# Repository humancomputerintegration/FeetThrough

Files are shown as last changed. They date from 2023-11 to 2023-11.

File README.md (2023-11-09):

# FeetThrough: Electrotactile Foot Interface that Preserves Real-World Sensations

This is the repository for PCB schematics and code for electrical stimulation used in the "FeetThrough: Electrotactile Foot Interface that Preserves Real-World Sensations" paper (ACM UIST2023).

**Summary**: FeetThrough is an open-source device that allows you to control external applications. Its hardware is built on an ESP32 microcontroller (you can use your favorite microcontroller), a custom-built multiplexer, and an electrical stimulator (we used the medical-grade Rehastim). We provide schematics for electrodes, multiplexers, and simple Python codes for electrical stimulation. By implementing a multiplexer and preparing a stimulator, you can test electrical stimulation for feet. Regarding the details of the electrode design, please refer to our paper.

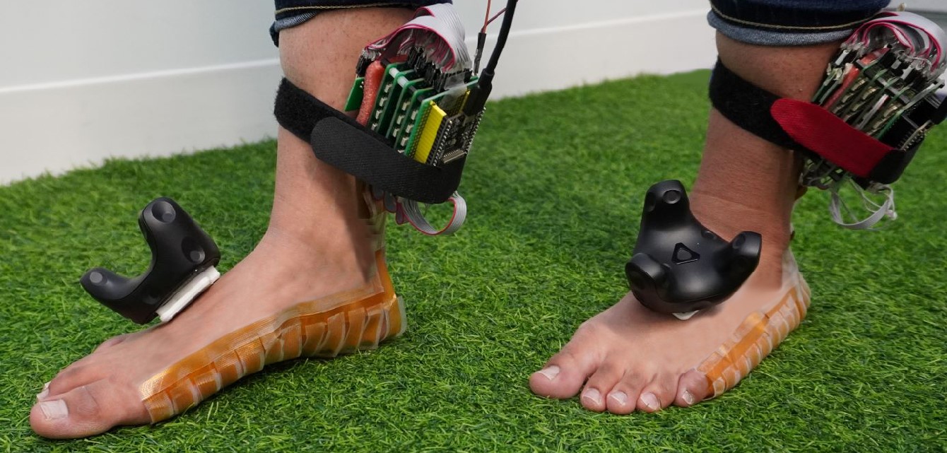
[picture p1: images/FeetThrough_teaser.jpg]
FeetThrough_image


## hardware

We share schematics of multiplexer board, flexible electrodes, and connector of the electrodes.

-  multiplexer: `hardware/photorelay_multiplexer`
   - This multiplexer is mainly consisted of shift registers (74HC595) and high-voltage photorelays (TLP176GA), and half-bridge configuration is created for each electrode

- electrodes: `hardware/electrodes` and `hardware/flexible_pcb_connector`
  - to use flexible electrodes, flexible PCB connector (FPC) is needed to deliver stimulation. We designed the end of the electrodes for this connector (FH12-30S-0.5SH(55), [mouser](https://mou.sr/3Qu7VoI)).
  - `app_electrodes_top` and `app_electrodes_bottom` are the final prototype of the electrodes to deliver stimulation to the whole sole. (To use 30-ch connector, the electrodes are separated in half)
  - To test the stimulator, you do not have to create flexible PCB electrodes. You can also use gel electrodes (often used for EMS) and other types of the electrodes if they are able to connect to the multiplexer

- stimulator (current source)
  - While we used the medical-grade RehaStim, you can use other electrical stimulators such as [RehaMove](https://github.com/humancomputerintegration/rehamove-integration-lib), [openEMSstim](https://github.com/PedroLopes/openEMSstim), [Electro-Tactile Display Kit for Fingertip (Kajimoto 2021)](https://ieeexplore.ieee.org/abstract/document/9517192).
  - connect the current source to `V+` and `V-` in the circuit.
  - We show another example of implementation with [a stimulator of Kajimoto 2021](https://ieeexplore.ieee.org/abstract/document/9517192)
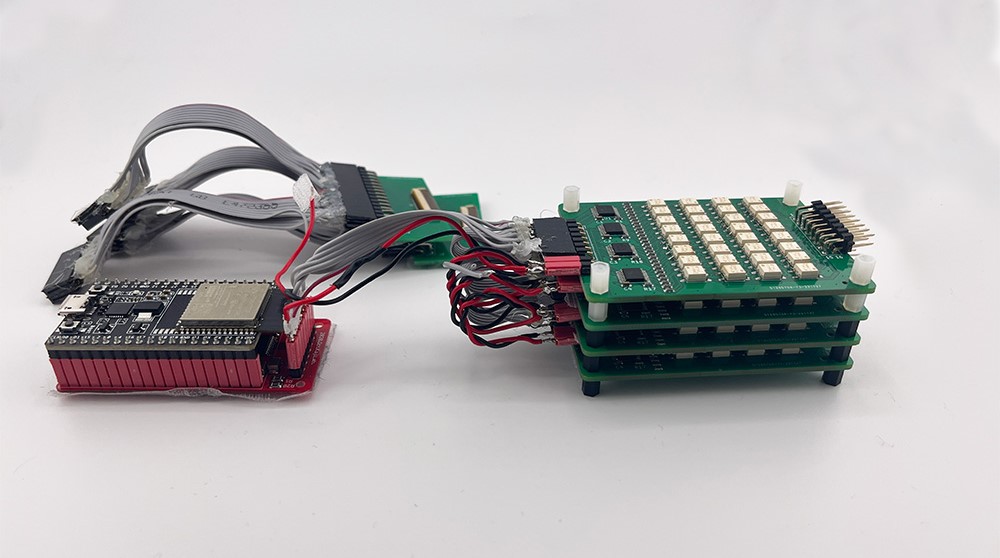
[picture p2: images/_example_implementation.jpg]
another_example_of_implementation
  - 

## source code

We share software code to stimulate multiple electrodes. To use the code, you have to prepare your stimulator and implement client for it. This code was developed for Windows 11

- client: `code/simple_stimulation`
  - `main.py`: simple controller of electrical stimulation
  - `custom_serial.py`: client for microcontroller of multiplexer
  - `photo_relay_switching.py`: Each channel of the multiplexer has three states (HIGH (V+), LOW (V-), OPEN (not connected)). This program manages and changes the states of multiplexer in software
  - `electro_stimulator.py`: client for electrical stimulator. This program controlls stimulation frequency and synchronize the timing between multiplexing and stimulator. 

in `electro_stimulator.py`, please change the code to use your stimulator

```python:electro_stimulator.py
# client for electrical stimulator ----- 
# NEED IMPLEMENTATION
client = ## please implement a client for your stimulator
## ------------------ 
```

```python:electro_stimulator.py
# --- send one pulse ---
# NEED IMPLEMENTATION
# client.write()
# --------
```

## how to use

- upload `arduino/multiplexer_esp32` to a microcontroller (ESP32 DevKitC 32E, [mouser](https://mou.sr/3GRjfHH)) through Arduino Software
  - before running the code, check and change `baudrate` and `com port` in `custom_serial.py`
- connect multiplexer and electrical stimulator to your PC
- run `main.py` in `code/simple_stimulation`

## contact

For any questions about this repository, please contact Keigo Ushiyama (ushiyama@kaji-lab.jp)

## citation

When using or building upon this work in an academic publication, please consider citing as follows:

Keigo Ushiyama and Pedro Lopes. 2023. FeetThrough: Electrotactile Foot Interface that Preserves Real-World Sensations. In Proceedings of the 36th Annual ACM Symposium on User Interface Software and Technology (UIST '23). Association for Computing Machinery, New York, NY, USA, Article 10, 1–11. https://doi.org/10.1145/3586183.3606808

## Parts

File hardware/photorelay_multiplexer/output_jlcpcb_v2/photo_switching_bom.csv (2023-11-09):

Comment | Designator | Footprint | JLCPCB Part #
0.1u | C1,C2,C3,C4 | Capacitor_SMD:C_0603_1608Metric | C14663
signals | J1 | Connector_PinSocket_2.54mm:PinSocket_1x07_P2.54mm_Vertical | C2932672
output | J2 | Connector_PinSocket_2.54mm:PinSocket_2x08_P2.54mm_Vertical | C239348
source | J3 | Connector_PinSocket_2.54mm:PinSocket_1x02_P2.54mm_Vertical | C2905414
470 | R1,R2,R3,R4,R5,R6,R7,R8,R9,R10,R11,R12,R13,R14,R15,R16,R17,R18,R19,R20,R21,R22,R23,R24,R25,R26,R27,R28,R29,R30,R31,R32 | Resistor_SMD:R_0603_1608Metric | C23179
74HC595 | U1,U10,U19,U20 | Package_SO:TSSOP-16_4.4x5mm_P0.65mm | C273642
TLP176GA | U2,U3,U4,U5,U6,U7,U8,U9,U11,U12,U13,U14,U15,U16,U17,U18,U21,U22,U23,U24,U25,U26,U27,U28,U29,U30,U31,U32,U33,U34,U35,U36 | keigo_custom_footprint:TLP176GA | C516859

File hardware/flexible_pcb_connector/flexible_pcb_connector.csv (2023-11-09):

Comment | Designator | Footprint | LCSC
Conn_01x30 | J1 | Connector_FFC-FPC:Hirose_FH12-30S-0.5SH_1x30-1MP_P0.50mm_Horizontal | C506793
Conn_01x30 | J2 | Connector_PinSocket_2.54mm:PinSocket_2x15_P2.54mm_Vertical

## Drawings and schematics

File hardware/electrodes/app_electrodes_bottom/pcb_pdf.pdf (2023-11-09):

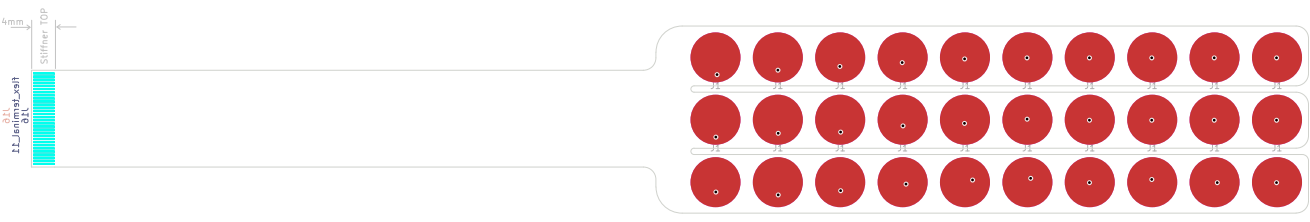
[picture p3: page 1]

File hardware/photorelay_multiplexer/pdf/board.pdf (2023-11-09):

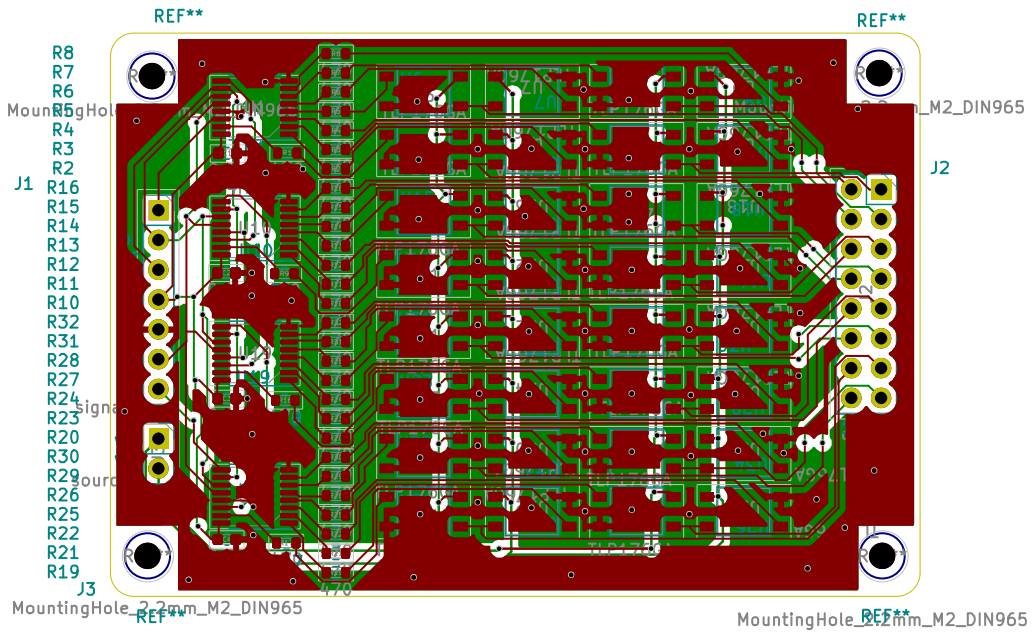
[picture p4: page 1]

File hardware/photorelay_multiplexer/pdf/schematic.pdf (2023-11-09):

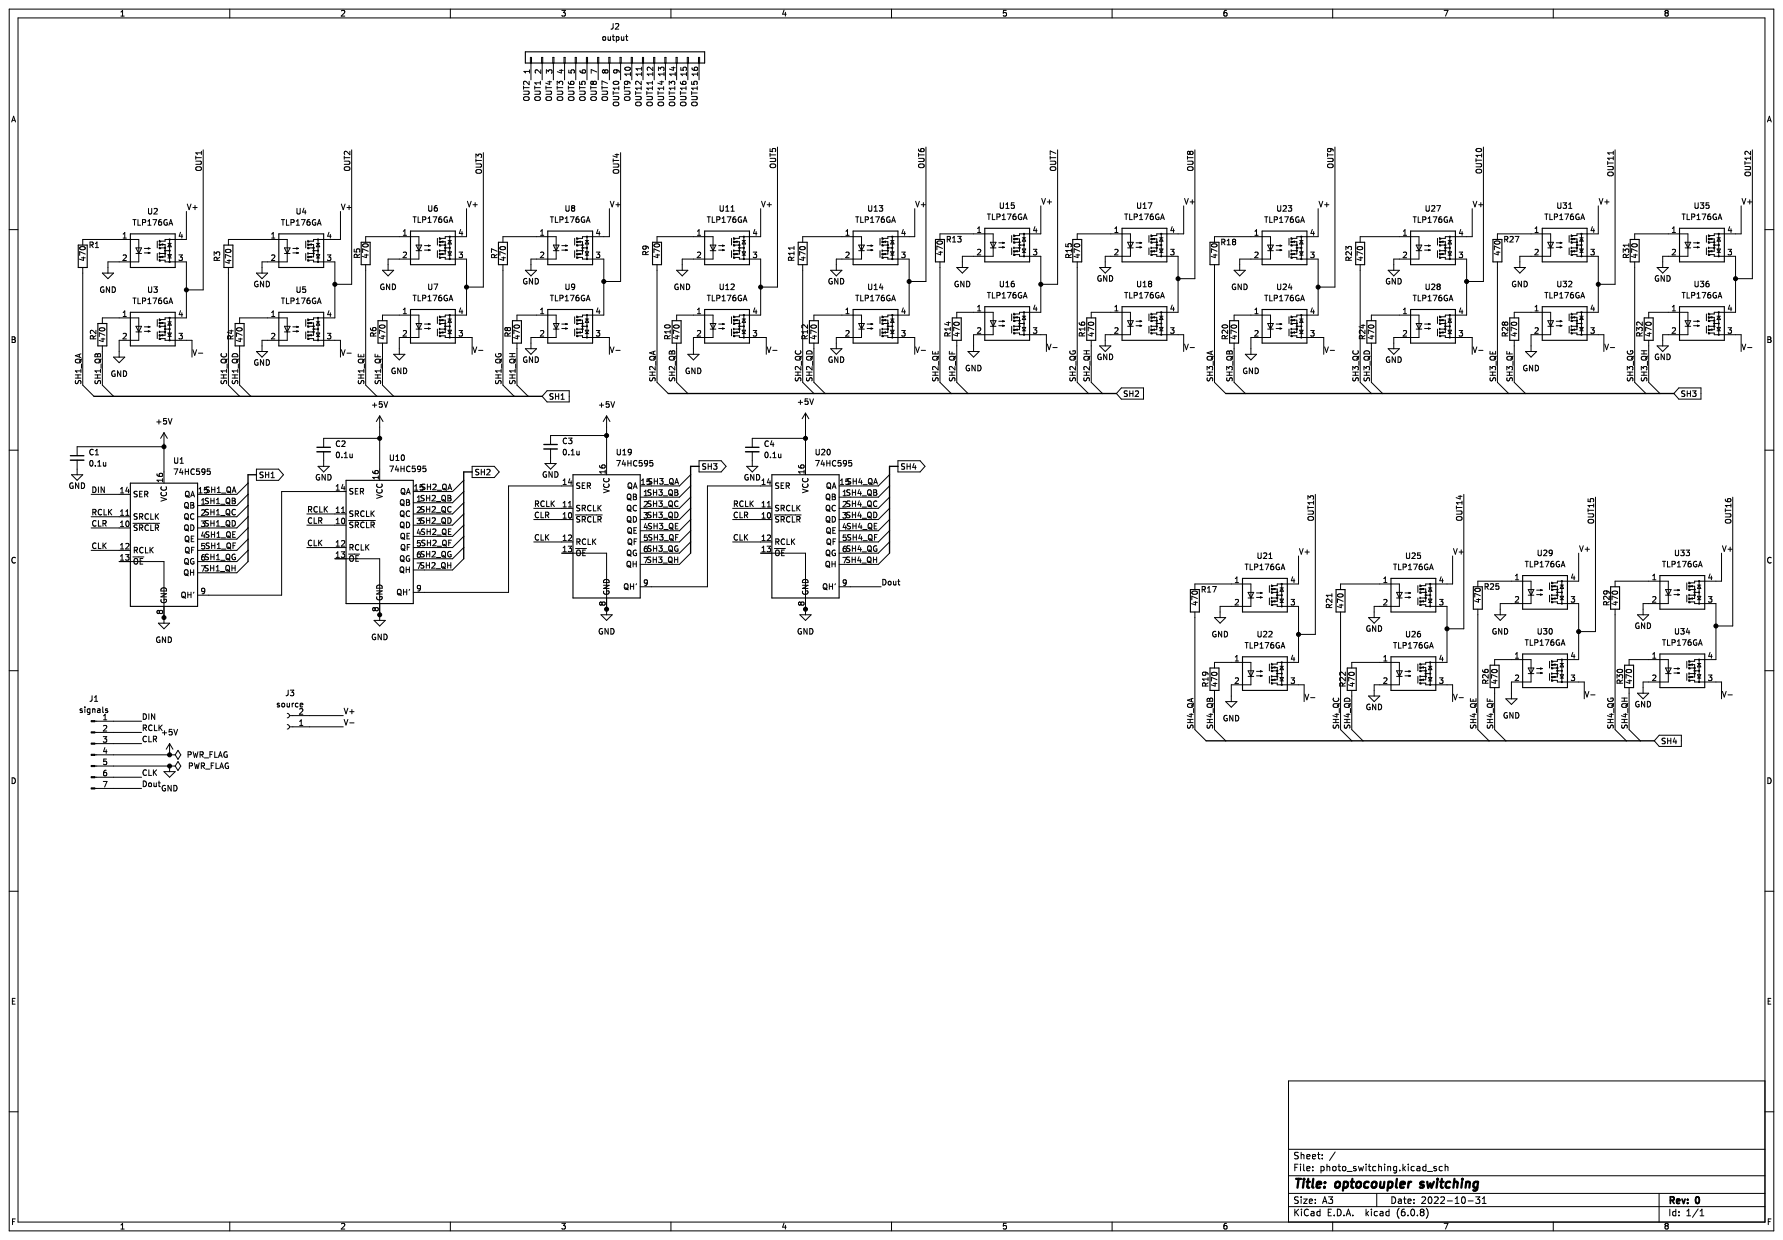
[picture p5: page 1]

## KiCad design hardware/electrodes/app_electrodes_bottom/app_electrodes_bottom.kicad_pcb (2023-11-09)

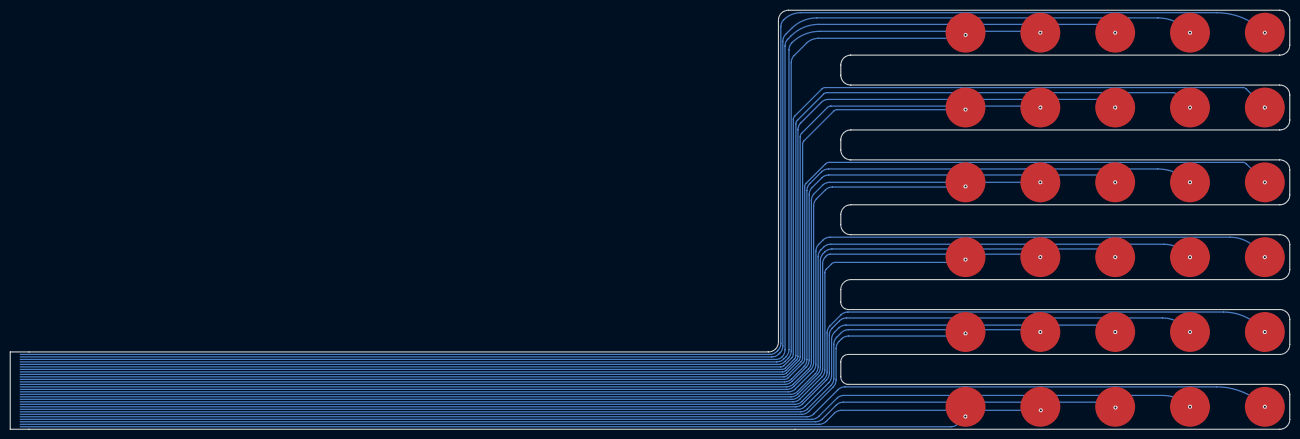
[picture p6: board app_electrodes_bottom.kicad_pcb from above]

Board: 2 copper layers, 256.5 x 84.0 mm, 31 parts (1 on the bottom side), 30 nets.

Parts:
J2, J3, J4, J5, J6, J8, J9, J10, J11, J12, J14, J15, J17, J18, J19, J21, J22, J23, J24, J25, J27, J28, J29, J30, J31, J32, J33, J34, J35, J36: electrode_pad; electrode_pad_smd
J16: flex_terminal_11; flex_hirose_30

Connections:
unnamed: J6.1, J16.1
unnamed: J8.10, J16.10
unnamed: J16.11, J19.11
unnamed: J16.12, J18.12
unnamed: J16.13, J17.13
unnamed: J15.14, J16.14
unnamed: J14.15, J16.15
unnamed: J5.2, J16.2
unnamed: J4.3, J16.3
unnamed: J3.4, J16.4
unnamed: J2.5, J16.5
unnamed: J12.6, J16.6
unnamed: J11.7, J16.7
unnamed: J10.8, J16.8
unnamed: J9.9, J16.9
unnamed: J16.16, J25.16
unnamed: J16.17, J24.17
unnamed: J16.18, J23.18
unnamed: J16.19, J22.19
unnamed: J16.20, J21.20
unnamed: J16.21, J31.21
unnamed: J16.22, J30.22
unnamed: J16.23, J29.23
unnamed: J16.24, J28.24
unnamed: J16.25, J27.25
unnamed: J16.26, J36.26
unnamed: J16.27, J35.27
unnamed: J16.28, J34.28
unnamed: J16.29, J33.29
unnamed: J16.30, J32.30

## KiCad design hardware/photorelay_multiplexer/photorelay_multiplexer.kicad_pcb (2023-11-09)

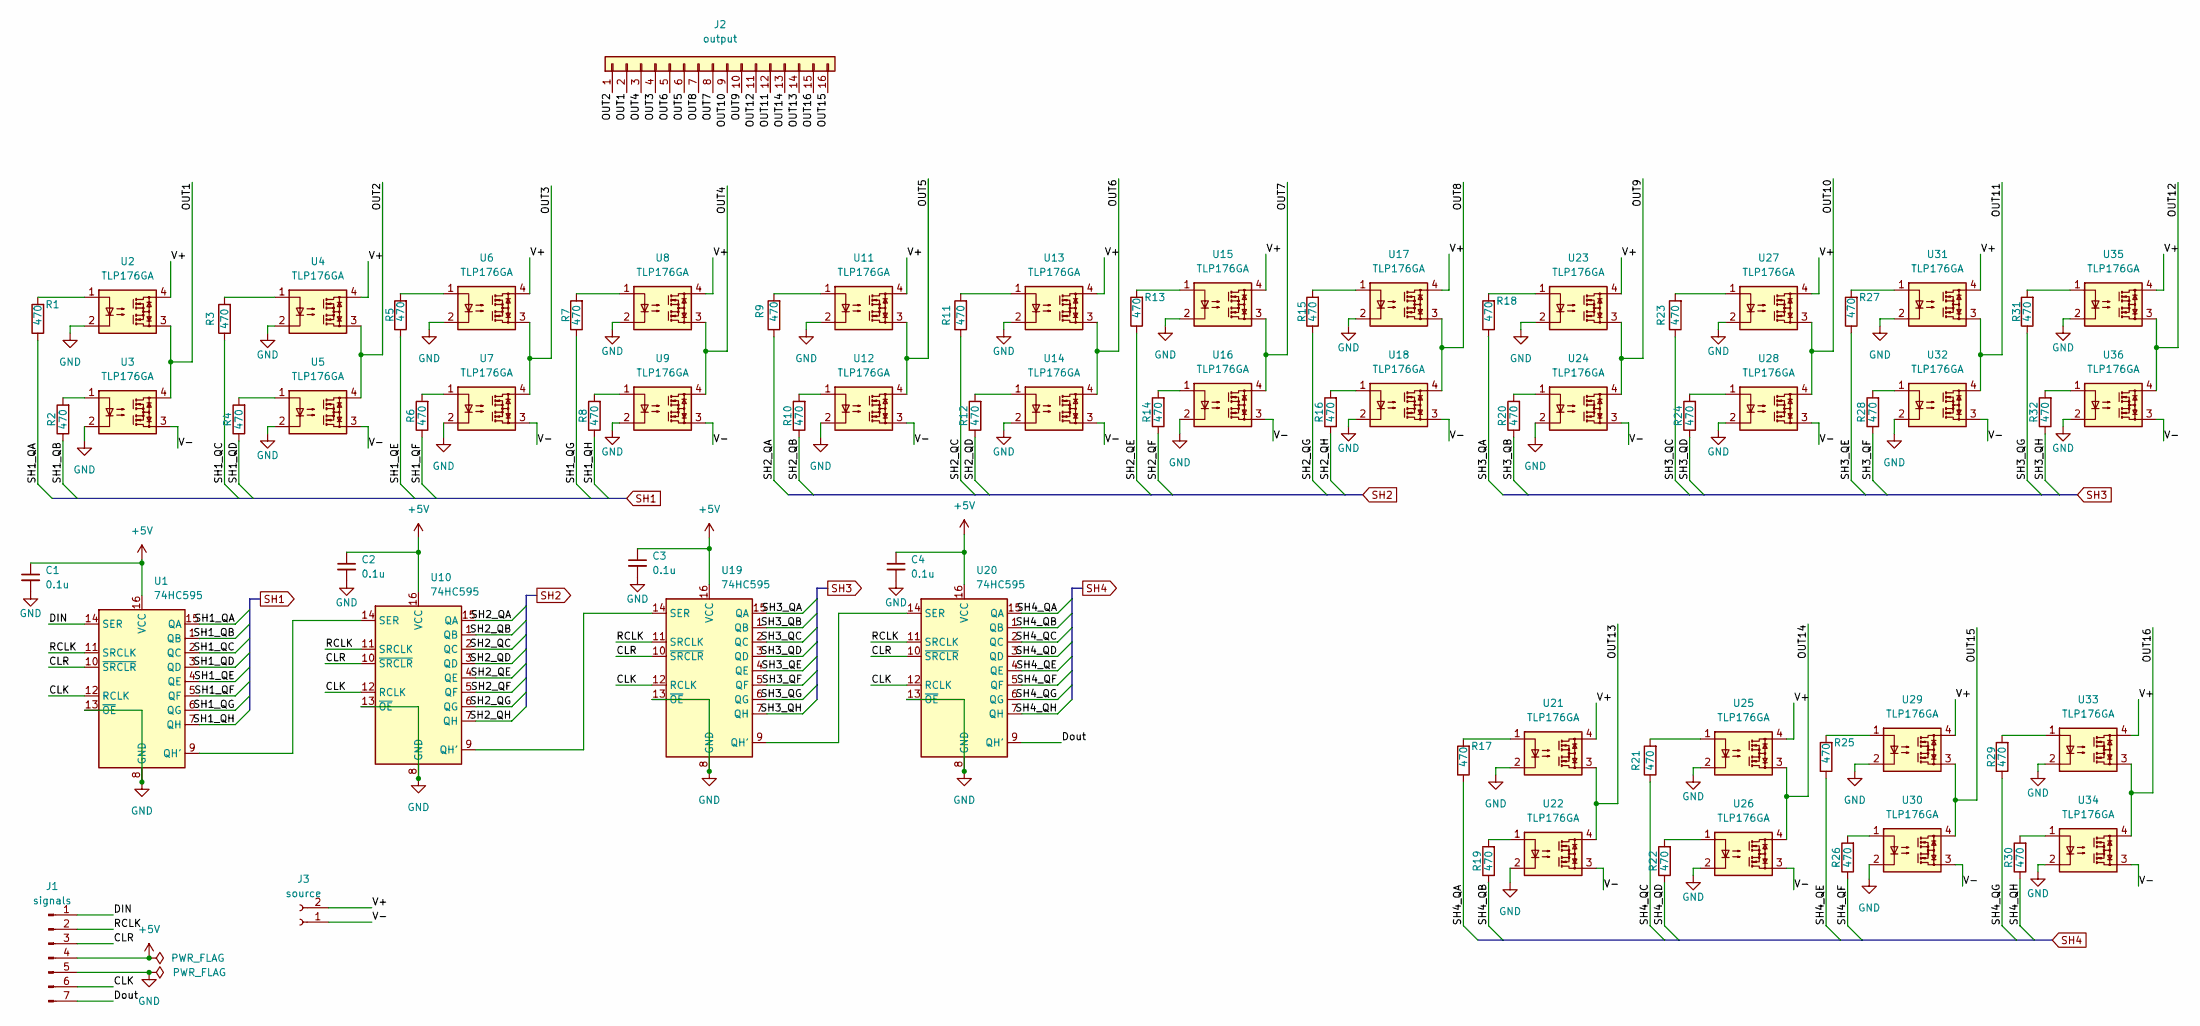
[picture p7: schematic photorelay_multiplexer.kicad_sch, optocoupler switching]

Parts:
C1, C2, C3, C4: 0.1u; C_0603_1608Metric
J1: signals; PinSocket_1x07_P2.54mm_Vertical
J2: output; PinSocket_2x08_P2.54mm_Vertical
J3: source; PinSocket_1x02_P2.54mm_Vertical
R1, R2, R3, R4, R5, R6, R7, R8, R9, R10, R11, R12, R13, R14, R15, R16, R17, R18, R19, R20, R21, R22, R23, R24, R25, R26, R27, R28, R29, R30, R31, R32: 470; R_0603_1608Metric
U1, U10, U19, U20: 74HC595; TSSOP-16_4.4x5mm_P0.65mm; LCSC C273642
U2: TLP176GA; LCSC C516859
U3, U4, U5, U6, U7, U8, U9, U11, U12, U13, U14, U15, U16, U17, U18, U21, U22, U23, U24, U25, U26, U27, U28, U29, U30, U31, U32, U33, U34, U35, U36: TLP176GA

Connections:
+5V: C1.1, C2.1, C3.1, C4.1, J1.4, U1.16 (VCC), U10.16 (VCC), U19.16 (VCC), U20.16 (VCC)
/CLK: J1.6, U1.12 (RCLK), U10.12 (RCLK), U19.12 (RCLK), U20.12 (RCLK)
/CLR: J1.3, U1.10 (~SRCLR), U10.10 (~SRCLR), U19.10 (~SRCLR), U20.10 (~SRCLR)
/DIN: J1.1, U1.14 (SER)
/Dout: J1.7, U20.9 (QH')
/OUT1: J2.2, U2.3, U3.4
/OUT2: J2.1, U4.3, U5.4
/OUT3: J2.4, U6.3, U7.4
/OUT4: J2.3, U8.3, U9.4
/OUT5: J2.6, U11.3, U12.4
/OUT6: J2.5, U13.3, U14.4
/OUT7: J2.8, U15.3, U16.4
/OUT8: J2.7, U17.3, U18.4
/OUT9: J2.10, U23.3, U24.4
/OUT10: J2.9, U27.3, U28.4
/OUT11: J2.12, U31.3, U32.4
/OUT12: J2.11, U35.3, U36.4
/OUT13: J2.14, U21.3, U22.4
/OUT14: J2.13, U25.3, U26.4
/OUT15: J2.16, U29.3, U30.4
/OUT16: J2.15, U33.3, U34.4
/RCLK: J1.2, U1.11 (SRCLK), U10.11 (SRCLK), U19.11 (SRCLK), U20.11 (SRCLK)
/SH1_QA: R1.1, U1.15 (QA)
/SH1_QB: R2.1, U1.1 (QB)
/SH1_QC: R3.1, U1.2 (QC)
/SH1_QD: R4.1, U1.3 (QD)
/SH1_QE: R5.1, U1.4 (QE)
/SH1_QF: R6.1, U1.5 (QF)
/SH1_QG: R7.1, U1.6 (QG)
/SH1_QH: R8.1, U1.7 (QH)
/SH2_QA: R9.1, U10.15 (QA)
/SH2_QB: R10.1, U10.1 (QB)
/SH2_QC: R11.1, U10.2 (QC)
/SH2_QD: R12.1, U10.3 (QD)
/SH2_QE: R13.1, U10.4 (QE)
/SH2_QF: R14.1, U10.5 (QF)
/SH2_QG: R15.1, U10.6 (QG)
/SH2_QH: R16.1, U10.7 (QH)
/SH3_QA: R18.1, U19.15 (QA)
/SH3_QB: R20.1, U19.1 (QB)
/SH3_QC: R23.1, U19.2 (QC)
/SH3_QD: R24.1, U19.3 (QD)
/SH3_QE: R27.1, U19.4 (QE)
/SH3_QF: R28.1, U19.5 (QF)
/SH3_QG: R31.1, U19.6 (QG)
/SH3_QH: R32.1, U19.7 (QH)
/SH4_QA: R17.1, U20.15 (QA)
/SH4_QB: R19.1, U20.1 (QB)
/SH4_QC: R21.1, U20.2 (QC)
/SH4_QD: R22.1, U20.3 (QD)
/SH4_QE: R25.1, U20.4 (QE)
/SH4_QF: R26.1, U20.5 (QF)
/SH4_QG: R29.1, U20.6 (QG)
/SH4_QH: R30.1, U20.7 (QH)
/V+: J3.2, U2.4, U4.4, U6.4, U8.4, U11.4, U13.4, U15.4, U17.4, U21.4, U23.4, U25.4, U27.4, U29.4, U31.4, U33.4, U35.4
/V-: J3.1, U3.3, U5.3, U7.3, U9.3, U12.3, U14.3, U16.3, U18.3, U22.3, U24.3, U26.3, U28.3, U30.3, U32.3, U34.3, U36.3
GND: C1.2, C2.2, C3.2, C4.2, J1.5, U1.8 (GND), U1.13 (~OE), U2.2, U3.2, U4.2, U5.2, U6.2, U7.2, U8.2, U9.2, U10.8 (GND), U10.13 (~OE), U11.2, U12.2, U13.2, U14.2, U15.2, U16.2, U17.2, U18.2, U19.8 (GND), U19.13 (~OE), U20.8 (GND), U20.13 (~OE), U21.2, U22.2, U23.2, U24.2, U25.2, U26.2, U27.2, U28.2, U29.2, U30.2, U31.2, U32.2, U33.2, U34.2, U35.2, U36.2
unnamed: R1.2, U2.1
unnamed: R2.2, U3.1
unnamed: R3.2, U4.1
unnamed: R4.2, U5.1
unnamed: R5.2, U6.1
unnamed: R6.2, U7.1
unnamed: R7.2, U8.1
unnamed: R8.2, U9.1
unnamed: R9.2, U11.1
unnamed: R10.2, U12.1
unnamed: R11.2, U13.1
unnamed: R12.2, U14.1
unnamed: R13.2, U15.1
unnamed: R14.2, U16.1
unnamed: R15.2, U17.1
unnamed: R16.2, U18.1
unnamed: R17.2, U21.1
unnamed: R18.2, U23.1
unnamed: R19.2, U22.1
unnamed: R20.2, U24.1
unnamed: R21.2, U25.1
unnamed: R22.2, U26.1
unnamed: R23.2, U27.1
unnamed: R24.2, U28.1
unnamed: R25.2, U29.1
unnamed: R26.2, U30.1
unnamed: R27.2, U31.1
unnamed: R28.2, U32.1
unnamed: R29.2, U33.1
unnamed: R30.2, U34.1
unnamed: R31.2, U35.1
unnamed: R32.2, U36.1
unnamed: U1.9 (QH'), U10.14 (SER)
unnamed: U10.9 (QH'), U19.14 (SER)
unnamed: U19.9 (QH'), U20.14 (SER)

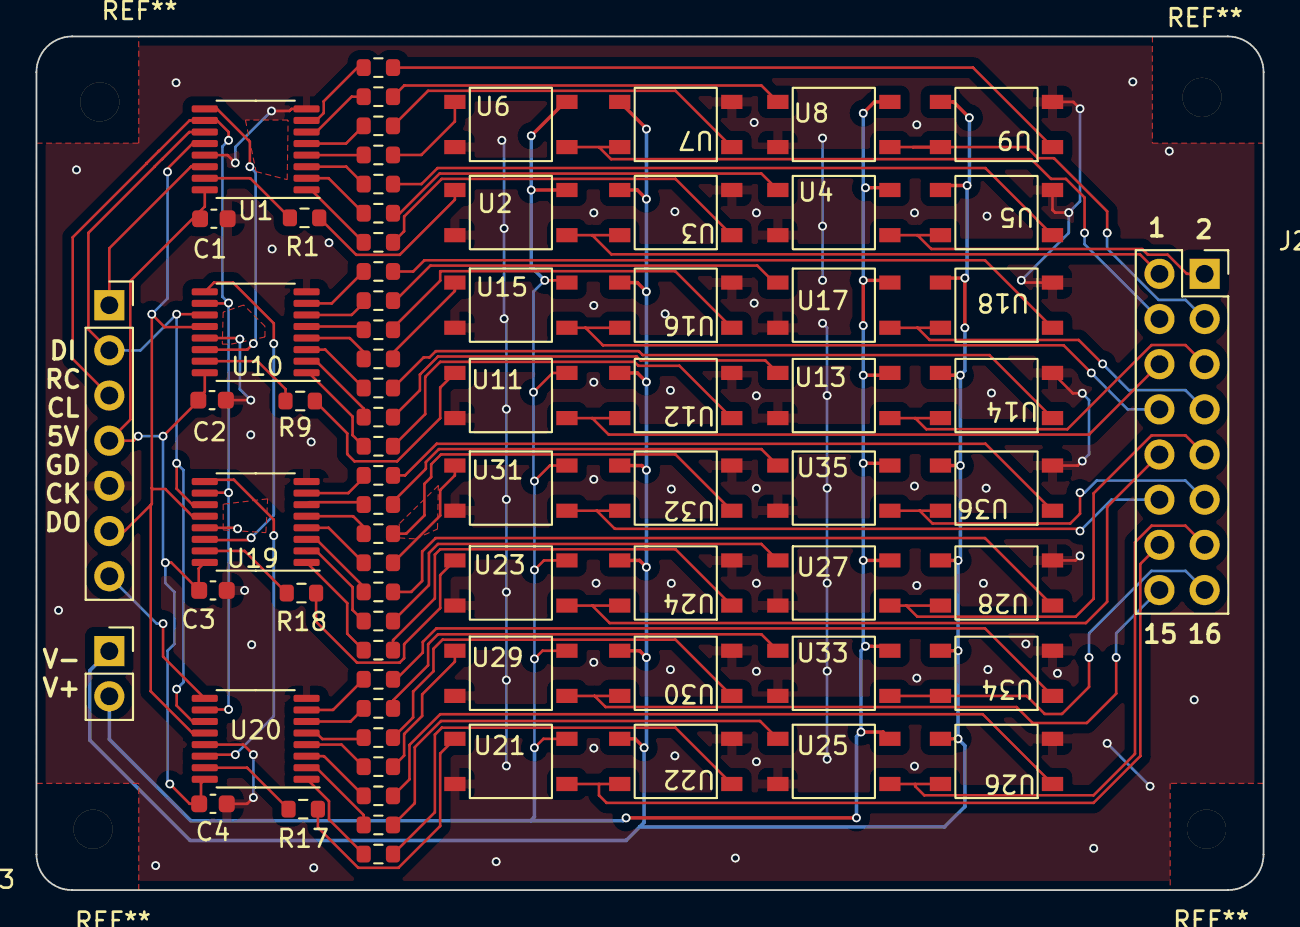
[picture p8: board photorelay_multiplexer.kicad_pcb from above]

Board: 2 copper layers, 69.0 x 48.0 mm, 75 parts (0 on the bottom side), 92 nets.

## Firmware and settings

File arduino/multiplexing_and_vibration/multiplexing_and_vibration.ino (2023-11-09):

// ----
// esp32 devkit c
// ---
#include <SPI.h>

// headers
const int ELECTRO = 0xFF;
const int VIBRO = 0xFE;

// for shift registers (optocoupler switching)
const int SR_SER = 32;
const int SR_CLK = 33;
const int SR_RCLK = 25;
const int SR_CLR = 26;
const int SR_OE = 27;

const int STATE_OPEN = 0;
const int STATE_GND = 1;
const int STATE_HIGH = 2;

// change this when you changed the number of boards!!
const int register_num = (8 * 4) * 4;
int register_state[register_num] = { 0 };

const int channel_num = register_num / 2;
int channel_state[channel_num] = { STATE_OPEN };
// -----


// for DACs and LRAs
// HSPI
const int m_HSCK = 14;
const int m_HMISO = 12;
const int m_HMOSI = 13;
const int m_HCS = 15;

// VSPI
const int m_VSCK = 18;
const int m_VMISO = 19;
const int m_VMOSI = 23;
const int m_VCS = 5;

// chip select by myself
const int m_CS1 = 16;
const int m_CS2 = 17;
const int SPI_FREQ = 10 * 1000 * 1000;

const int MAX_AMP = 1023;  // LTC1660 - 10bit
const int BASE_OFFSET = (1.0 / 5.0) * MAX_AMP;
const int BASE_AMP = 1023 - BASE_OFFSET;

const int CHANNELS = 16;  //10;


const int VIBRATION = 0xFF;
const int CALIBRATION = 0xFE;

const int TABLE_LEN = 10000;
int table_index = 0;
const int sampling_rate = 10000;
int vibration_intensities[CHANNELS];
//float sin_table[TABLE_LEN];
float square_table[TABLE_LEN];
hw_timer_t *counter_timer;


// stimulation parameters
int frequency = 175;  // Hz
int vibrate_flags[CHANNELS];

void IRAM_ATTR increment_index() {
  int increment = (int)(frequency * ((double)TABLE_LEN / (double)sampling_rate));
  table_index = (table_index + increment) % TABLE_LEN;
}

// ------ electrical stimulation -----
void set_all_channel() {
  digitalWrite(SR_CLK, LOW);
  digitalWrite(SR_RCLK, LOW);

  for (int i = 0; i < channel_num; i++) {
    if (channel_state[i] == STATE_OPEN) {
      // LOW
      digitalWrite(SR_SER, LOW);
      digitalWrite(SR_CLK, HIGH);
      digitalWrite(SR_CLK, LOW);
      // LOW
      digitalWrite(SR_SER, LOW);
      digitalWrite(SR_CLK, HIGH);
      digitalWrite(SR_CLK, LOW);
    } else if (channel_state[i] == STATE_HIGH) {
      // LOW
      digitalWrite(SR_SER, LOW);
      digitalWrite(SR_CLK, HIGH);
      digitalWrite(SR_CLK, LOW);
      // HIGH
      digitalWrite(SR_SER, HIGH);
      digitalWrite(SR_CLK, HIGH);
      digitalWrite(SR_CLK, LOW);
    } else if (channel_state[i] == STATE_GND) {
      // HIGH
      digitalWrite(SR_SER, HIGH);
      digitalWrite(SR_CLK, HIGH);
      digitalWrite(SR_CLK, LOW);
      // LOW
      digitalWrite(SR_SER, LOW);
      digitalWrite(SR_CLK, HIGH);
      digitalWrite(SR_CLK, LOW);
    }
  }

  digitalWrite(SR_SER, LOW);
  digitalWrite(SR_RCLK, HIGH);
  digitalWrite(SR_RCLK, LOW);
}

// ------

void setup() {
  // --- for shift registers
  pinMode(SR_SER, OUTPUT);
  pinMode(SR_CLK, OUTPUT);
  pinMode(SR_RCLK, OUTPUT);
  pinMode(SR_CLR, OUTPUT);
  pinMode(SR_OE, OUTPUT);
  digitalWrite(SR_OE, LOW);
  digitalWrite(SR_CLR, HIGH);

  for (int i = 0; i < channel_num; i++) {
    channel_state[i] = STATE_OPEN;
  }
  set_all_channel();
  // --- for DACs + Vibrators
  pinMode(m_CS1, OUTPUT);
  pinMode(m_CS2, OUTPUT);
  // chip select
  digitalWrite(m_CS1, HIGH);  // dac1
  digitalWrite(m_CS2, HIGH);  // dac2

  // prepare table for square wave
  for (int i = 0; i < TABLE_LEN; i++) {
    if (i < TABLE_LEN / 2.0) {
      square_table[i] = 0;
    } else {
      square_table[i] = 1;
    }
  }

  for (int i = 0; i < CHANNELS; i++) {
    vibration_intensities[i] = MAX_AMP;
    vibrate_flags[i] = 0;
  }

  SPI.begin(m_VSCK, m_VMISO, m_VMOSI, m_VCS);
  SPI.setHwCs(false);  // manage cs by myself


  // there was noise on signals. I quitted using hw_timer
  //  counter_timer = timerBegin(0, 80, true);
  //  timerAttachInterrupt(counter_timer, &increment_index, true);
  //  timerAlarmWrite(counter_timer, 1000000 / sampling_rate, true);
  //  timerAlarmEnable(counter_timer);

  Serial.begin(921600);
  // Serial.begin(1500000);

  LTC1660_clear();
}

void LTC1660_clear() {
  int channel = 0x0F;
  int transfer_data = ((channel & 0x0F) << 12) | ((0 & 0x03FF) << 2);
  digitalWrite(m_CS1, LOW);
  digitalWrite(m_CS2, LOW);
  SPI.beginTransaction(SPISettings(SPI_FREQ, MSBFIRST, SPI_MODE0));
  SPI.write16(transfer_data);
  SPI.endTransaction();
  digitalWrite(m_CS1, HIGH);
  digitalWrite(m_CS2, HIGH);
}

void LTC1660_transfer(int channel, int d) {
  // if channel is larger than 8, change CS pin
  int CSpin = m_CS1;
  if (channel > 8) {
    channel -= 8;
    CSpin = m_CS2;
  }

  int transfer_data = ((channel & 0x0F) << 12) | ((d & 0x03FF) << 2);
  digitalWrite(CSpin, LOW);
  SPI.beginTransaction(SPISettings(SPI_FREQ, MSBFIRST, SPI_MODE0));
  SPI.write16(transfer_data);
  SPI.endTransaction();
  digitalWrite(CSpin, HIGH);
}


void vibrate_by_flags(int duration) {
  double timer = 0;
  // if frequency = 175 Hz, 175 pulses in 1 sec.
  int pulse_count = round((duration / 1000.0) / (1.0 / frequency));

  int counter = 0;
  int pulse = 0;
  while (counter <= pulse_count) {
    double delay_us = (1000000.0 / (double)frequency) / 2.0;
    double st = micros();
    for (int i = 0; i < CHANNELS; i++) {
      if (vibrate_flags[i] == 1) {
        // VIBRATE (send a signal)
        int amp = vibration_intensities[i] * 1;  //* square_table[table_index];
        int channel = i + 1;
        LTC1660_transfer(channel, amp);
      }
    }

    delay_us -= micros() - st;
    delayMicroseconds(delay_us);  // delay microseconds

    st = micros();
    delay_us = (1000000.0 / (double)frequency) / 2.0;
    LTC1660_clear();
    delay_us -= (micros() - st);
    delayMicroseconds(delay_us);
    counter++;
  }
  LTC1660_clear();
}

void vibrate(int channel, int duration) {
  // channel: 1 ~ 8, 9, 10
  // duration: ms
  //  int u_tick = 1; // 1 us
  // 250 ms -> 250 * 1000 us
  //  int vib_len = (int)(duration * 1000.0 / (double) u_tick);
  // due to latency of SPI, this may not work well.

  int pulse_count = round((duration / 1000.0) / (1.0 / frequency));
  int index = channel - 1;
  int counter = 0;
  int pulse = 0;
  while (counter <= pulse_count) {
    double delay_us = (1000000.0 / (double)frequency) / 2.0;
    double st = micros();

    // VIBRATE (send a signal)
    int amp = vibration_intensities[index] * 1;  //* square_table[table_index];
    LTC1660_transfer(channel, amp);


    delay_us -= micros() - st;
    delayMicroseconds(delay_us);  // delay microseconds

    st = micros();
    delay_us = (1000000.0 / (double)frequency) / 2.0;
    LTC1660_clear();
    delay_us -= (micros() - st);
    delayMicroseconds(delay_us);

    counter++;
  }
  LTC1660_clear();
}


int vib_index = 0;
void loop() {


  // each channel (N byte) + header (1 byte)
  if (Serial.available() >= CHANNELS) {
    int header = Serial.read();
    if (header == ELECTRO) {
      byte state = 0;
      for (int i = 0; i < channel_num; i++) {
        state = Serial.read();
        if (state < 0 || state > 2) {
          // out of range. something went wrong
          continue;
        }
        channel_state[i] = state;
      }
      set_all_channel();
    } else if (header == VIBRO) {
      for (int i = 0; i < CHANNELS; i++) {
        int amplitude = Serial.read();  // 0 ~ 255
        if (amplitude > 0) {
          vibrate_flags[i] = 1;
        } else {
          vibrate_flags[i] = 0;
        }
        vibration_intensities[i] = amplitude << 2;  // 2bit shift -> 0 ~ 1023;
      }

      int duration = Serial.read() * 100;  // changed from pulses to duration
      vibrate_by_flags(duration);

      for (int i = 0; i < CHANNELS; i++) {
        vibrate_flags[i] = 0;
      }
    }
  }


  // debug -- vibration
  //  int duration = 500;
  //  vibrate_flags[vib_index] = 1;
  //  vibrate_by_flags(duration);
  //  vibrate_flags[vib_index] = 0;
  //  vib_index = (vib_index + 1) % CHANNELS;
  //  delay(500);

  // debug -- measurement
  //  int sleep = 200;
  //  channel_state[0] = STATE_HIGH;
  //  channel_state[1] = STATE_GND;
  //  channel_state[30] = STATE_HIGH;
  //  channel_state[31] = STATE_GND;
  //  set_all_channel();
  //  delayMicroseconds(sleep);
  //  channel_state[0] = STATE_GND;
  //  channel_state[1] = STATE_HIGH;
  //  channel_state[30] = STATE_GND;
  //  channel_state[31] = STATE_HIGH;
  ////  channel_state[32] = STATE_GND;
  //  set_all_channel();
  //  delayMicroseconds(sleep);
  // ----
}
